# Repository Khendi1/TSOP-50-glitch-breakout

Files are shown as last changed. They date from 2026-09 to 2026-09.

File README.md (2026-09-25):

# TSOP-50 Glitch Breakout (FFC)

A thin, foldable piggyback breakout for circuit-bending / hardware-glitching
a TSOP-50 RAM or flash chip **in place** without desoldering it. The castellated edges
fold down over the sides of a live chip and solder to its leads, while the flat top
face exposes a large copper landing for every pin so you can probe, short, or inject on
each net.

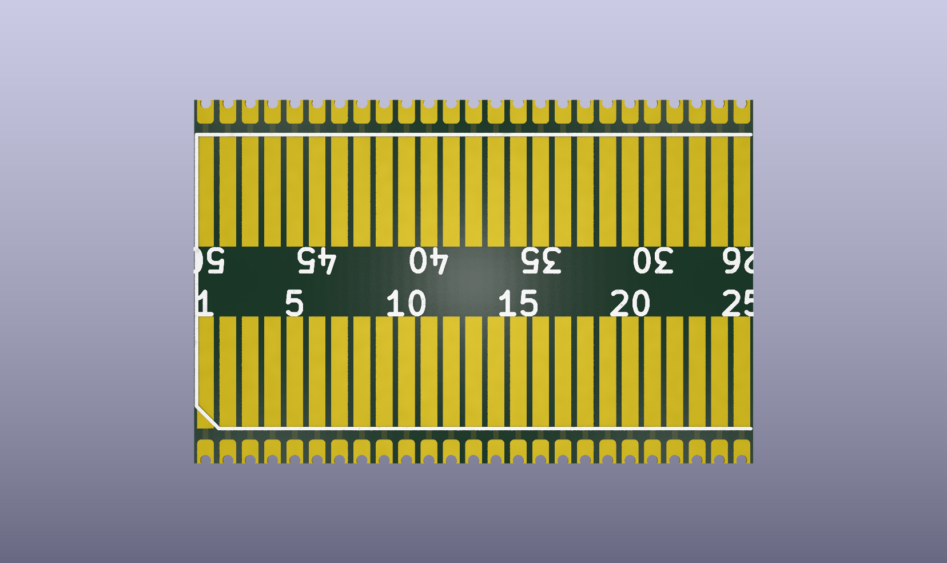
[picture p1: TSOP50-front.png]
TSOP-50 glitch breakout -- top copper render


---

## What it is

- A **20 x 13 mm**, 2-layer breakout sized to sit directly on top of a **TSOP-50** package
  (dual-row, 50 pins, 0.8 mm pitch).
- Two inner rows of **0.6 x 4 mm** exposed copper **fingers** (25 per row, 6.5 mm row-to-row)
  that mate to the chip's two rows of leads.
- **Plated, castellated half-holes** along **both** long edges (0.4 mm drill on the edge cut,
  0.8 mm pitch) that become **bendable solder tabs**.
- Built on **0.11 mm (2-layer) polyimide flex** so the edges physically fold down over the chip.

The idea: get solid, wire-and-probe-friendly access to every pin of a RAM/flash chip that is
already soldered into a device, so you can experiment with data corruption, address/clock
glitching, DQ/strobe injection, and other circuit-bending effects.

---

## How it works

The board is a **piggyback interposer**. It goes on *top* of the target chip, which stays
soldered in its host device.

```
              exposed copper fingers = probe/wire points (top face)
                     |    |    |    |    |    |
   +-----------------+----+----+----+----+----+-----------------+   <- 0.11 mm flex breakout
   |                     (over the chip body)                   |
   +--+                                                      +--+
      | castellated tab                      castellated tab |     <- long edges fold DOWN
      v (solder to lead)                    (solder to lead) v
   ===+========== TSOP-50 (still in circuit) ==========+=========
      +-- gull-wing lead                  gull-wing lead --+
   ------------------------ host device PCB ------------------------
```

1. **Locate** the target TSOP-50 on the victim board. Its leads exit the two long sides.
2. **Lay the breakout on top**, centered over the chip body, so the two inner finger rows line
   up over the two rows of leads and the castellated tabs overhang the lead tips.
3. **Fold each long edge down** along the sides of the chip. Because the board is thin flex,
   the castellated tabs come down beside the corresponding leads.
4. **Solder each tab to its lead** (or to the host pad the lead sits on). Now every pin is
   brought up to the top face.
5. **Work on the top face:** each finger is a large, exposed landing above the chip body -- tack
   wires, clip probes, cut/jumper, or inject signals there instead of on the fragile 0.8 mm
   leads.

The tabs do the mechanical/electrical connection; the top-face fingers give you room to work.

---

## Board specs

| Property | Value |
|---|---|
| Outline | 20.0 x 13.0 mm |
| Layers | 2 (F.Cu / B.Cu) |
| Substrate | **Polyimide flex** |
| Total thickness  | **0.11 mm** |
| Target package | TSOP-50, dual row, **0.8 mm pitch** |
| Signal fingers | 0.6 x 4 mm, 25 per row, two rows 6.5 mm apart (top-face copper) |
| Castellations | 0.4 mm drill, 0.6 x 1.5 mm pads, both long edges, 0.8 mm pitch |
| Pin-1 marker | Chamfered corner + silk numbering down the center |
| Finish | ENIG (recommended for fine-pitch hand-soldering) |

**Physical stackup (0.11 mm, defined in `TSOP50.kicad_pcb`):**

| Layer | Material | Thickness |
|---|---|---|
| F.Cu | copper (1 oz) | 0.035 mm  |
| dielectric 1 | **Polyimide** | 0.040 mm  |
| B.Cu | copper (1 oz) | 0.035 mm  |
| **Total** | | **0.110 mm** |

> **Note:** these sub-thicknesses are nominal -- the exact flex build (core thickness, copper
> weight, coverlay) is set by your fab's flex process. On the order form, select **flex /
> polyimide** and **0.11 mm** total; treat the KiCAD stackup as the design intent, not a
> guaranteed cross-section. Thin flex + 1 oz copper is stiff to fold; drop to 0.5 oz copper if
> you want the edges to bend more easily.

---

## Orientation & pinout

- **Pin 1** is at the **chamfered corner** (bottom-left in the render). Numbering follows the
  standard dual-row IC convention: down one long row, then back along the other -- pins **1-25**
  along the bottom row, **26-50** along the top.
- Every pad is numbered **by position**, so each castellation matches the finger on its own
  edge (finger + tab share a net for all 50 pins).
- The center silkscreen labels **every 5th pin plus the corners**: `1, 5, 10, 15, 20, 25` on the
  bottom row and `26, 30, 35, 40, 45, 50` on the top -- readable at 0.8 mm pitch; count from the
  nearest marker.
- Both edges are populated with castellations so you can approach the chip from whichever side
  is accessible in the host device.

> **Note:** always verify against your specific chip's datasheet pinout before trusting any
> individual net. `board-render.png` above was captured before the silkscreen cleanup, so its
> center digits differ from the current board.

---

## Fabrication

Gerbers and drill files are pre-generated in [`manufacturing/`](manufacturing/):

```
manufacturing/
  TSOP50-F_Cu.gbr / TSOP50-B_Cu.gbr          top / bottom copper
  TSOP50-F_Mask.gbr / TSOP50-B_Mask.gbr      solder mask
  TSOP50-F_Paste.gbr / TSOP50-B_Paste.gbr    paste
  TSOP50-F_Silkscreen.gbr / TSOP50-B_Silkscreen.gbr
  TSOP50-Edge_Cuts.gbr                        board outline
  TSOP50-PTH-drl.gbr / TSOP50-drl.rpt         plated drills (castellations)
  TSOP50-job.gbrjob                           Gerber job file
```

> The pad renumbering did not move any copper, but the **silkscreen changed**, so the
> `*_Silkscreen.gbr` files are stale -- re-export from `TSOP50.kicad_pcb` before ordering.

When ordering:

- Order as **0.11 mm, 2-layer, polyimide flex** (not rigid FR4).
- Enable **castellated / edge-plated holes** (the tabs sit on the board edge).
- ENIG finish is recommended for reliable hand-soldering to fine-pitch leads.

---

## Circuit-bending / safety notes

This board is a tool for **intentional glitching** of hardware you own and are authorized to
modify. A few practical cautions:

- Shorting or injecting on RAM/flash lines can **crash, corrupt, or brick** the target and, in
  the worst case, damage the chip or host. Expect the unexpected -- that's the point.
- Keep injected voltages within the target's rails; a stray 5 V onto a 1.8/3.3 V bus will kill
  the chip.
- Power supplies and glitching can bite back -- current-limit your bench supply and don't leave
  a bent device unattended.
- The 0.8 mm leads are delicate; solder to the **top-face fingers**, not repeatedly to the leads.

---

## Credits

Design inspired by **derWarst's Gl0tchpatch**, shared on the
[scanlines.xyz](https://scanlines.xyz/) circuit-bending community. This board is an independent
take on the same idea -- a fold-down piggyback breakout for glitching memory in place. Thanks to
derWarst for the concept.
